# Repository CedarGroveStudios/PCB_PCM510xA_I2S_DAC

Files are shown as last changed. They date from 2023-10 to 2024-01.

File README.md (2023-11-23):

# PCM510xA I2S Stereo DAC

### 

An I2S stereo audio DAC with an internal master clock PLL and a charge pump for direct-coupled ground-centered audio output.

[Adafruit Playground Article](https://adafruit-playground.com/u/CGrover/pages/pcm510xa-i2s-stereo-dac-breakout)

[Schematic](https://github.com/CedarGroveStudios/PCB_PCM510xA_I2S_DAC/blob/main/PCB/PCM510xA_I2S_DAC.pdf)

OSH Park PCB:
[https://oshpark.com/shared_projects/a6rQdBe2](https://oshpark.com/shared_projects/WVrOgntC)

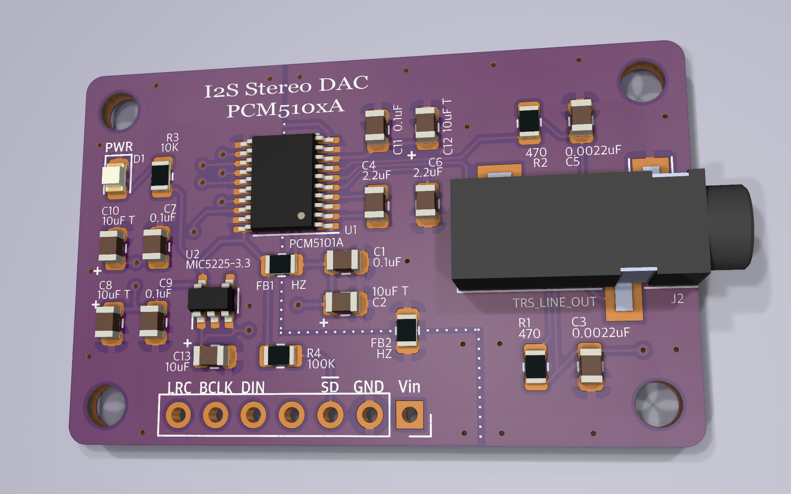
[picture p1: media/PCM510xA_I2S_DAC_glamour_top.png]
glamour photo


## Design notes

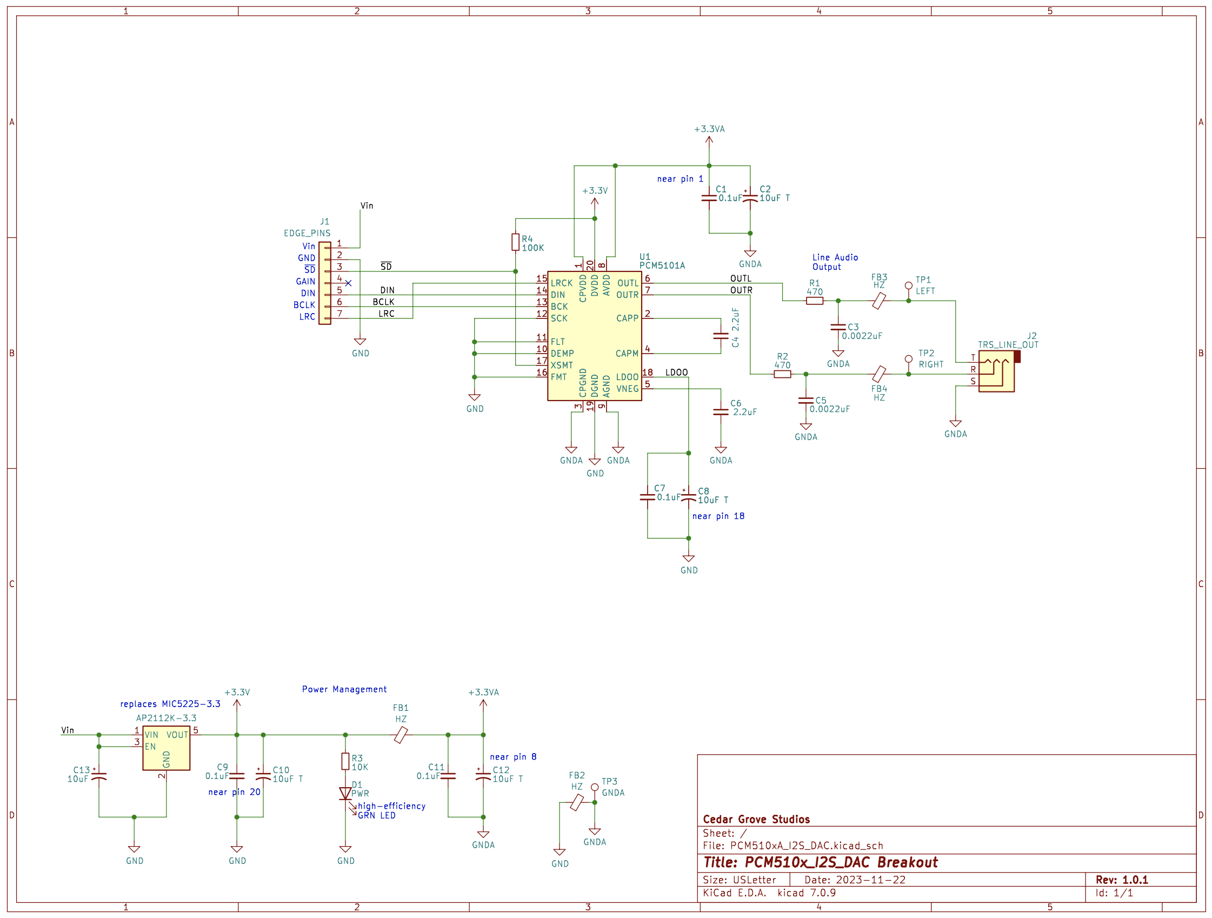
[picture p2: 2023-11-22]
media/PCM510xA_I2S_DAC_schematic.png

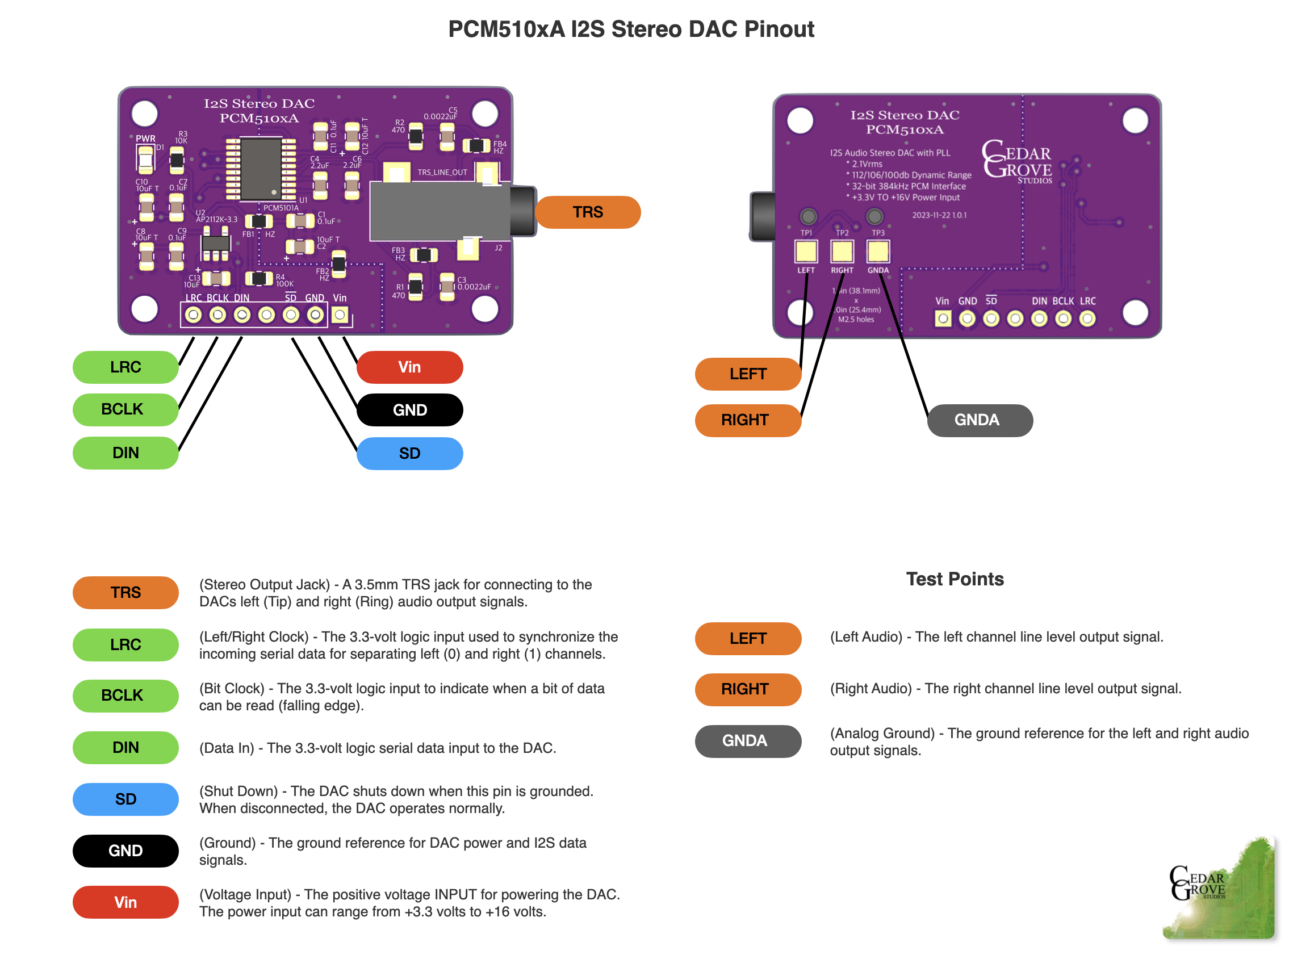
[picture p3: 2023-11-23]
media/PCM510xA_I2S_DAC_pinout.png

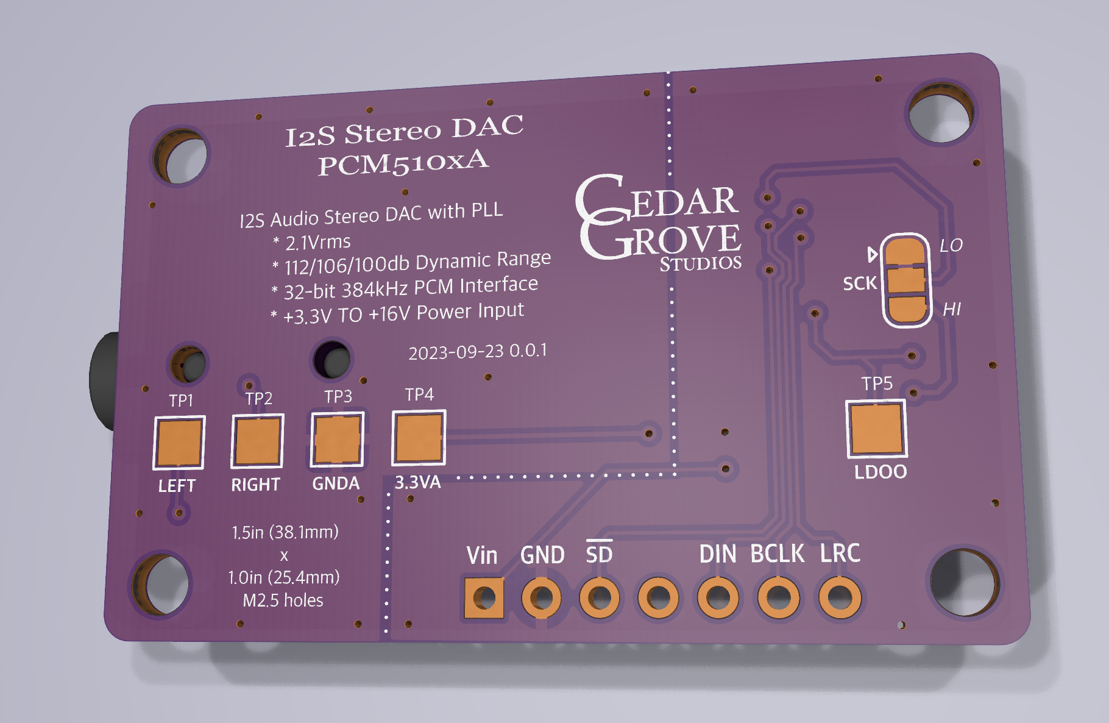
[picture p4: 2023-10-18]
media/PCM510xA_I2S_DAC_glamour_bot.png

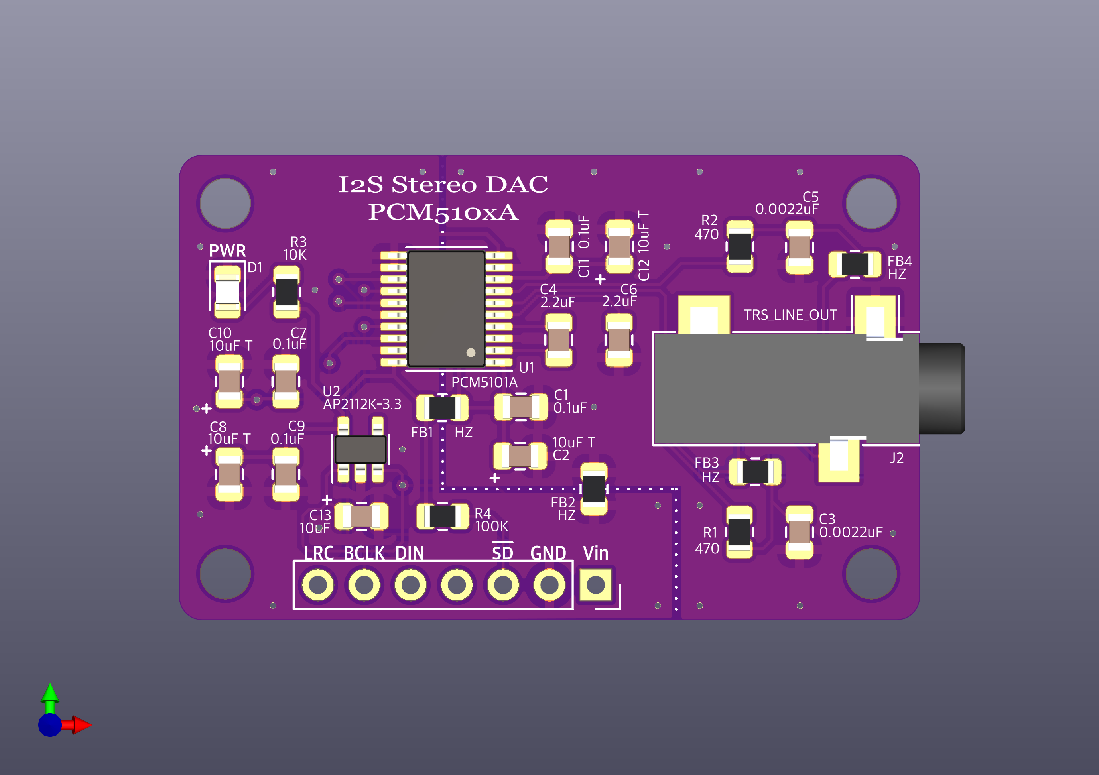
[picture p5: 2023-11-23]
media/PCM510xA_I2S_DAC_top_unrend.png

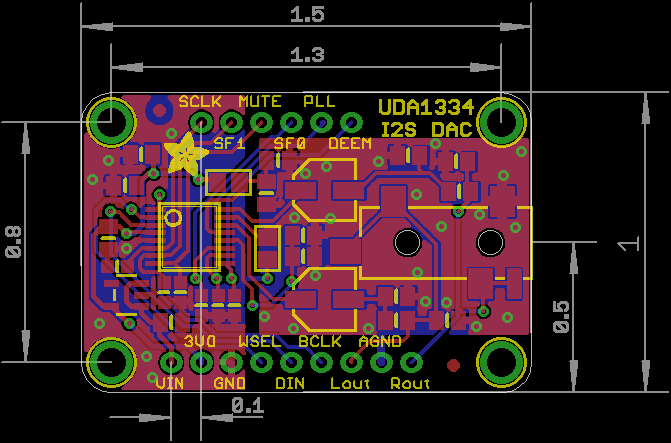
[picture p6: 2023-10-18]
media/adafruit_products_fabprint.png

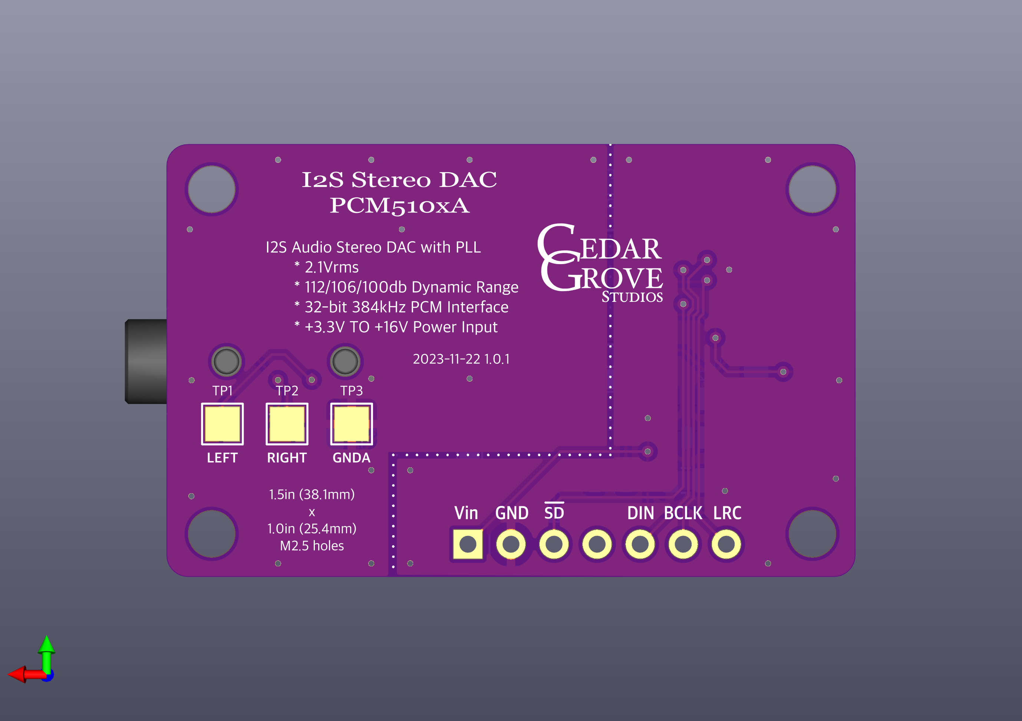
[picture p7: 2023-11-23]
media/PCM510xA_I2S_DAC_bot_unrend.png

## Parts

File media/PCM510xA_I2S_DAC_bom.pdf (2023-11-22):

### PCM510xA_I2S_DAC

Date: | Wednesday, November 22, 2023 at 11:30:16AM
Component Count: | 29
Item | Qty | Reference(s) | Value | LibPart | Footprint | Datasheet | DigiKey
1 | 4 | C1, C7, C9, C11 | 0.1uF | Device:C_Small | Capacitor_SMD:C_0805_2012Metric | ~
2 | 4 | C2, C8, C10, C12 | 10uF T | Device:C_Polarized_Small_US | Capacitor_SMD:C_0805_2012Metric | ~
3 | 2 | C3, C5 | 0.0022uF | Device:C_Small | Capacitor_SMD:C_0805_2012Metric | ~
4 | 2 | C4, C6 | 2.2uF | Device:C_Small | Capacitor_SMD:C_0805_2012Metric | ~
5 | 1 | C13 | 10uF | Device:C_Polarized_Small_US | Capacitor_SMD:C_0805_2012Metric | ~
6 | 1 | D1 | PWR | Device:LED | LED_SMD:LED_0805_2012Metric | ~ | 1497-XZCDGK54W-1VFCT-ND
7 | 4 | FB1, FB2, FB3, FB4 | HZ0805E601R | Device:FerriteBead_Small | Resistor_SMD:R_0805_2012Metric | ~ | 240-2399-1-ND
8 | 1 | J2 | TRS_LINE_OUT | Connector_Audio:AudioJack3 | Connector_Audio:Jack_3.5mm_CUI_SJ-3523-SMT_Horizontal | ~ | CP-3523SJCT-ND
9 | 2 | R1, R2 | 470 | Device:R_Small | Resistor_SMD:R_0805_2012Metric | ~
10 | 1 | R3 | 10K | Device:R_Small | Resistor_SMD:R_0805_2012Metric | ~
11 | 1 | R4 | 100K | Device:R_Small | Resistor_SMD:R_0805_2012Metric | ~
12 | 1 | U1 | PCM5101A | Audio:PCM5101A | Package_SO:TSSOP-20_4.4x6.5mm_P0.65mm | https://www.ti.com/lit/ds/symlink/pcm5101a.pdf | 296-36706-1-ND
13 | 1 | U2 | AP2112K-3.3 | Regulator_Linear:AP2112K-3.3 | Package_TO_SOT_SMD:SOT-23-5 | https://www.diodes.com/assets/Datasheets/AP2112.pdf

1

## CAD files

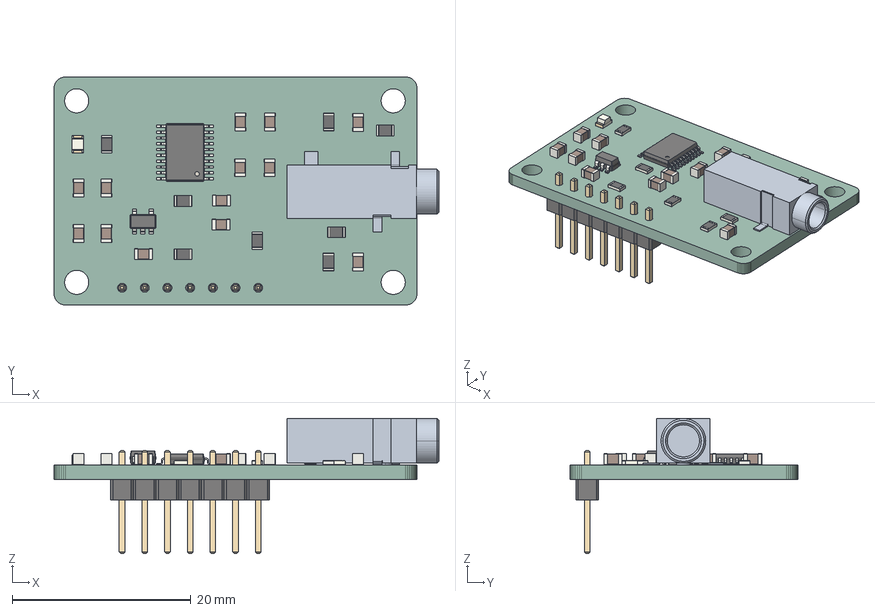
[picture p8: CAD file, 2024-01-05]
PCB/PCM510xA_I2S_DAC.step
43.1 x 25.5 x 15.1 mm
PCM510xA_I2S_DAC PCB

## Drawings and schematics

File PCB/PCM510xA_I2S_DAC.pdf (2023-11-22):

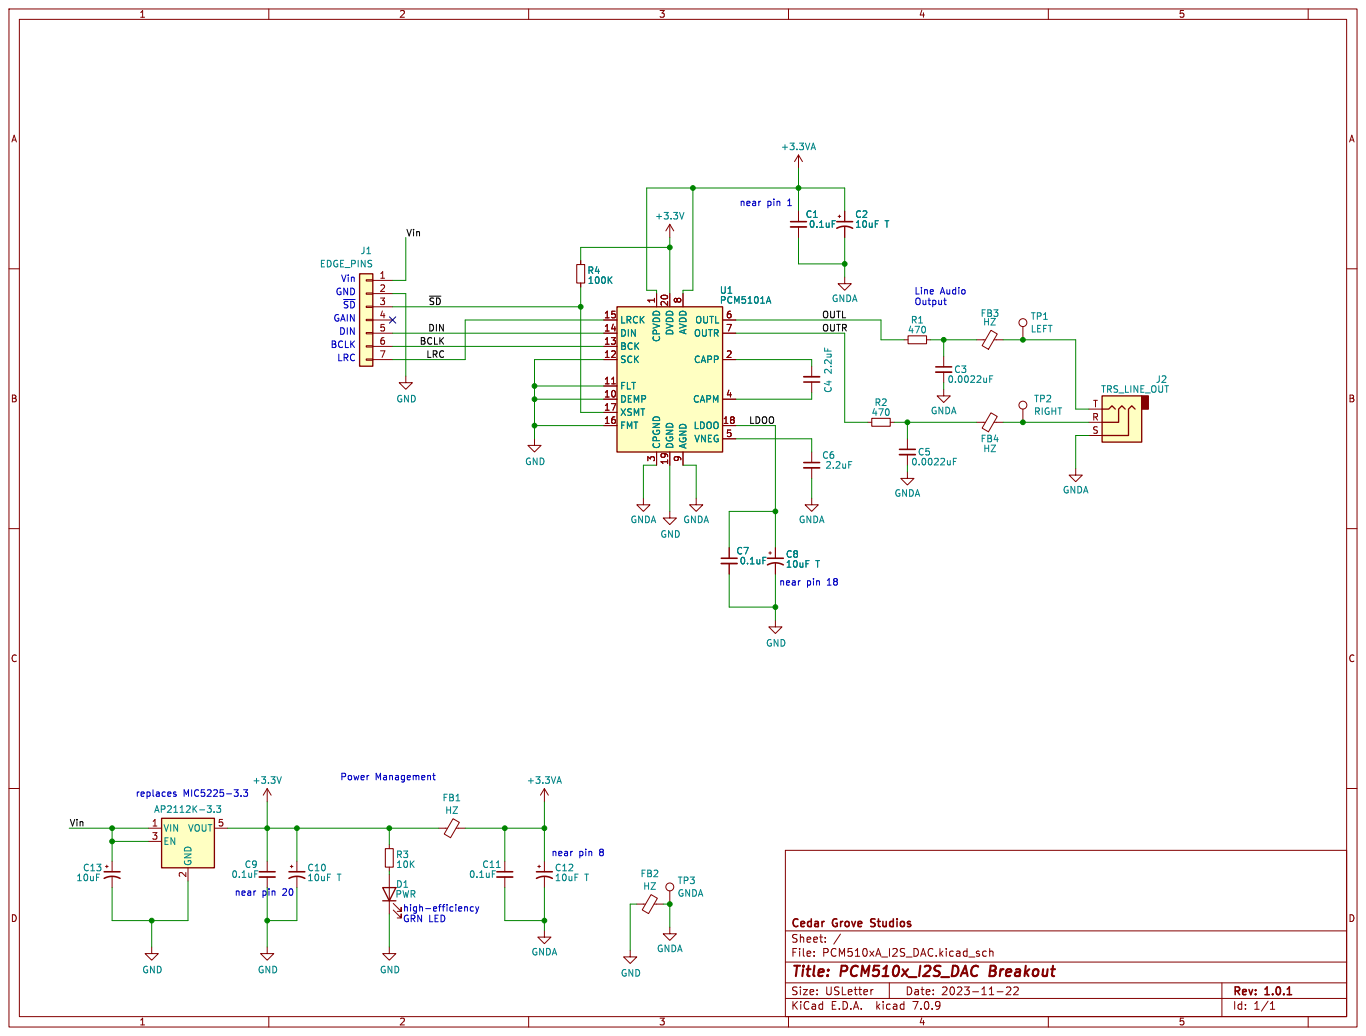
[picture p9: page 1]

1 DEMP 10 FLT 11 SCK 12 BCK 13 DIN 14

3 CAPM 4 VNEG 5 OUTL 6 OUTR 7 AVDD

near pin 8 Power Management

Id: 1/1 Title: PCM510x_I2S_DAC Breakout File: PCM510xA_I2S_DAC.kicad_sch Sheet: / Cedar Grove Studios GNDA GND GNDA C11

high-efficiency GRN LED

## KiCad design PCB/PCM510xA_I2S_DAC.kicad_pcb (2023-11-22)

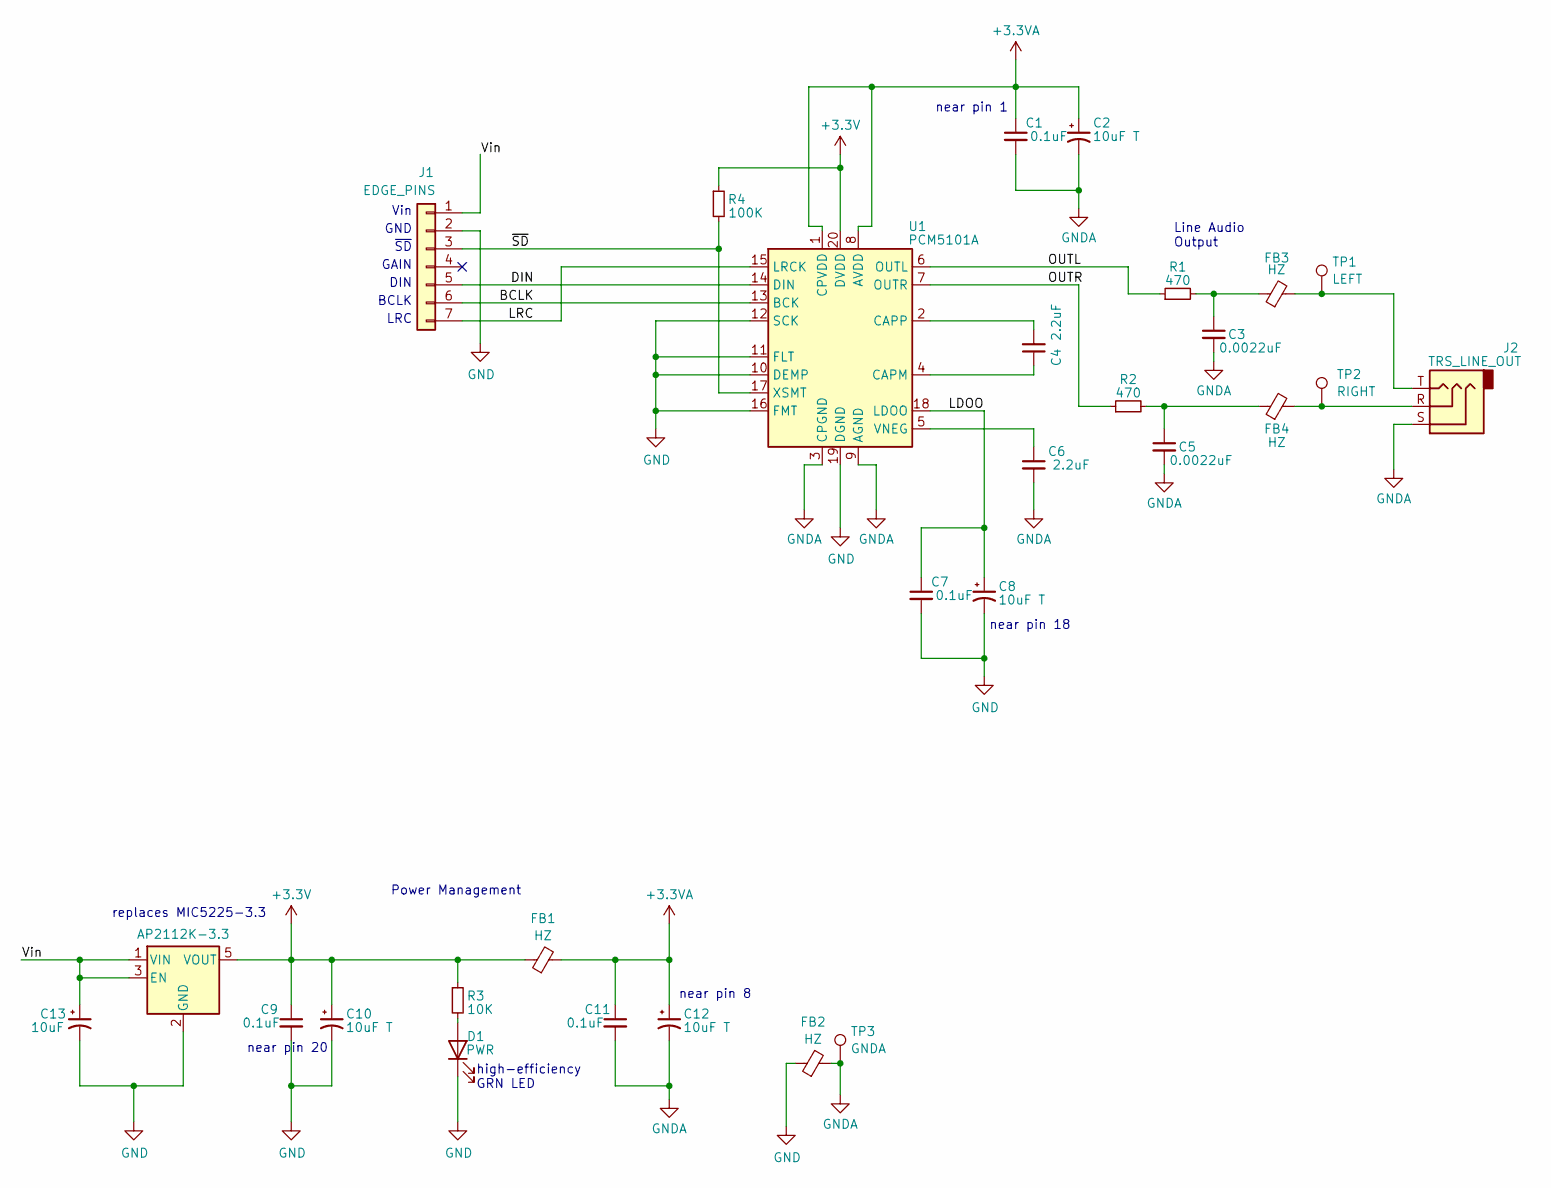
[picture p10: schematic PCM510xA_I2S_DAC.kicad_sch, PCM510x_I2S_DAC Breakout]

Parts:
C1, C7, C9, C11: 0.1uF; C_0805_2012Metric
C2, C8, C10, C12: 10uF T; C_0805_2012Metric
C3, C5: 0.0022uF; C_0805_2012Metric
C4, C6: 2.2uF; C_0805_2012Metric
C13: 10uF; C_0805_2012Metric
D1: PWR; LED_0805_2012Metric
FB1, FB2, FB3, FB4: HZ; R_0805_2012Metric
J1: EDGE_PINS; PinSocket_1x07_P2.54mm_Vertical
J2: TRS_LINE_OUT; Jack_3.5mm_CUI_SJ-3523-SMT_Horizontal
R1, R2: 470; R_0805_2012Metric
R3: 10K; R_0805_2012Metric
R4: 100K; R_0805_2012Metric
TP1: LEFT; TestPoint_Pad_2.0x2.0mm
TP2: RIGHT; TestPoint_Pad_2.0x2.0mm
TP3: GNDA; TestPoint_Pad_2.0x2.0mm
U1: PCM5101A; TSSOP-20_4.4x6.5mm_P0.65mm
U2: AP2112K-3.3; SOT-23-5

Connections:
+3.3V: C9.1, C10.1, FB1.1, R3.1, R4.1, U1.20 (DVDD), U2.5 (VOUT)
+3.3VA: C1.1, C2.1, C11.1, C12.1, FB1.2, U1.1 (CPVDD), U1.8 (AVDD)
/BCLK: J1.6, U1.13 (BCK)
/DIN: J1.5, U1.14 (DIN)
/LDOO: C7.1, C8.1, U1.18 (LDOO)
/LRC: J1.7, U1.15 (LRCK)
/OUTL: R1.1, U1.6 (OUTL)
/OUTR: R2.1, U1.7 (OUTR)
/Vin: C13.1, J1.1, U2.1 (VIN), U2.3 (EN)
/~SD: J1.3, R4.2, U1.17 (XSMT)
GND: C7.2, C8.2, C9.2, C10.2, C13.2, D1.1 (K), FB2.1, J1.2, U1.10 (DEMP), U1.11 (FLT), U1.12 (SCK), U1.16 (FMT), U1.19 (DGND), U2.2 (GND)
GNDA: C1.2, C2.2, C3.2, C5.2, C6.2, C11.2, C12.2, FB2.2, J2.S, TP3.1, U1.3 (CPGND), U1.9 (AGND)
unnamed: C3.1, FB3.1, R1.2
unnamed: C5.1, FB4.1, R2.2
unnamed: D1.2 (A), R3.2
unnamed: FB3.2, J2.T, TP1.1
unnamed: FB4.2, J2.R, TP2.1
unnamed: C4.1, U1.4 (CAPM)
unnamed: C4.2, U1.2 (CAPP)
unnamed: C6.1, U1.5 (VNEG)

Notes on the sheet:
replaces MIC5225-3.3
GND
high-efficiency GRN LED
LRC
near pin 1
Vin
DIN
Line Audio Output
near pin 18
near pin 20
Power Management
BCLK
GAIN
~{SD}
near pin 8

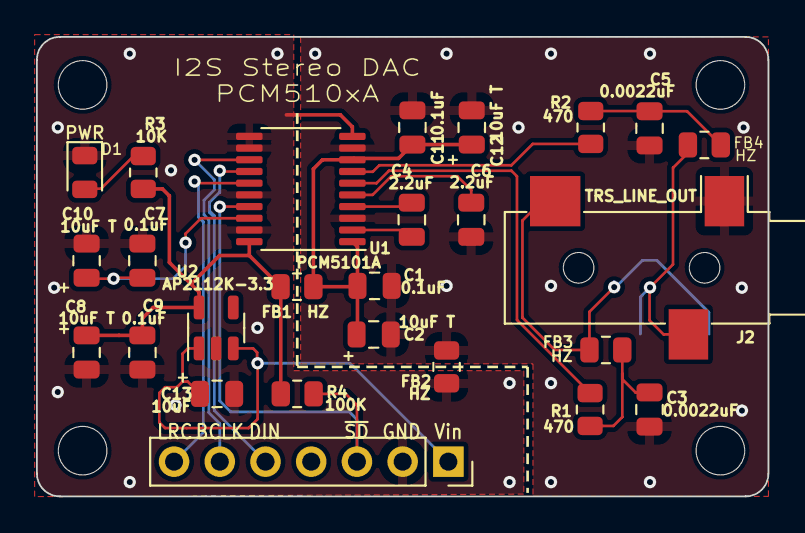
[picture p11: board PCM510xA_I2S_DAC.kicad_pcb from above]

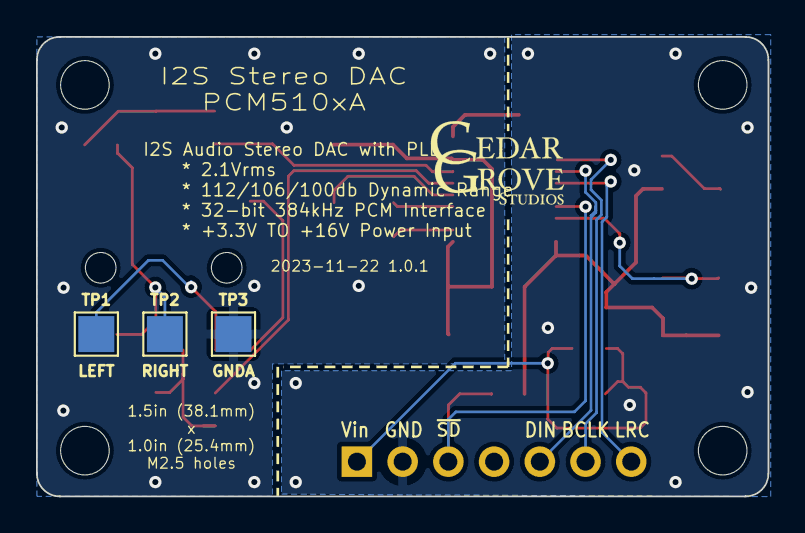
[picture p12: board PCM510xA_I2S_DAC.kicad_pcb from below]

Board: 2 copper layers, 40.6 x 25.5 mm, 29 parts (3 on the bottom side), 20 nets.

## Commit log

2023-10-18 initial repo load
    [PCM510xA_I2S_DAC-B_Cu.gbl, PCM510xA_I2S_DAC-B_Mask.gbs, PCM510xA_I2S_DAC-B_Silkscreen.gbo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]
2023-10-23 update to 1.0.0
    [PCM510xA_I2S_DAC-B_Cu.gbl, PCM510xA_I2S_DAC-B_Mask.gbs, PCM510xA_I2S_DAC-B_Silkscreen.gbo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]
2023-11-22 update 3.3v regulator
    [PCM510xA_I2S_DAC-B_Cu.gbl, PCM510xA_I2S_DAC-B_Mask.gbs, PCM510xA_I2S_DAC-B_Silkscreen.gbo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]
2023-11-22 update gerbers and bom
    [PCM510xA_I2S_DAC.csv]
2024-01-05 update design; update backups
    [PCM510xA_I2S_DAC.step]
